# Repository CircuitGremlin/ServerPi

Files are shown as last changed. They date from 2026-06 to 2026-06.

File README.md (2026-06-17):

[Information](#information)\
[Key features](#key-features)\
[Case](#case)\
[PCB](#pcb)\
[Bill of materials](#bill-of-materials)\
[Installation](#installation)\
[Led configuration](#led-configuration)\
[Oled stats](#oled-stats)\
[Known issues](#known-issues)\
[To do](#to-do)\
[Contribute](#contribute)

# Information
A few years ago, I built a server with a CM4, a CM4IO board and an asm1064 PCI-e card. With the release of the Raspberry Pi 5, I wanted to build a new server. I prefer the Geekworm X1009 to the Radxa Penta because it has five ports and the power connector is on the back.

This server case isn't the smallest, but I'm happy with it so far. It sits on my media unit and is always visible, so it needs to look good.

# Key features
- 149x194x88mm (width x depth x height(without feet))
- Supports 5x2.5" HDD up to 15mm on caddy's
- Access to the SD card, power button and LED on the side behind the ventilation grille.
- Custom PCB and software (Easy configure led's wia Webserver)
- Oled stats (https://github.com/CircuitGremlin/RPiOledStatsLuma)

## Case
[3D print files](/3d_print_files)<br />
[Plywood panel plans](/plywood_panel_plans)

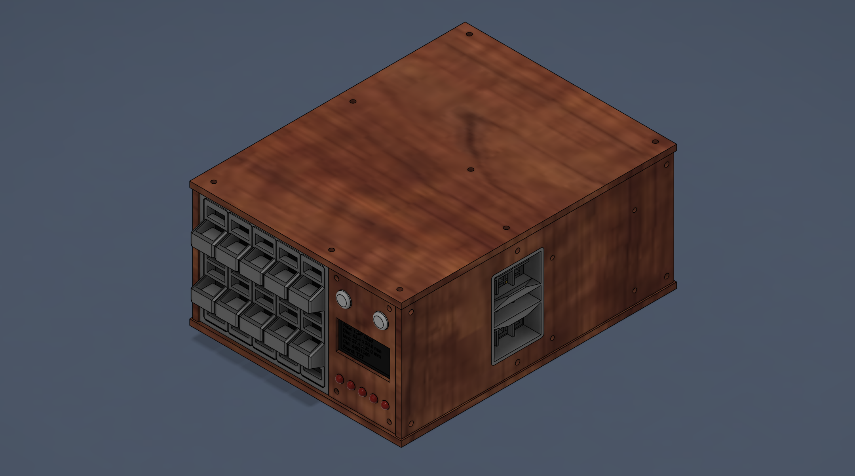
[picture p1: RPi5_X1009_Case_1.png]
picture alt RPi5 X1009 Case

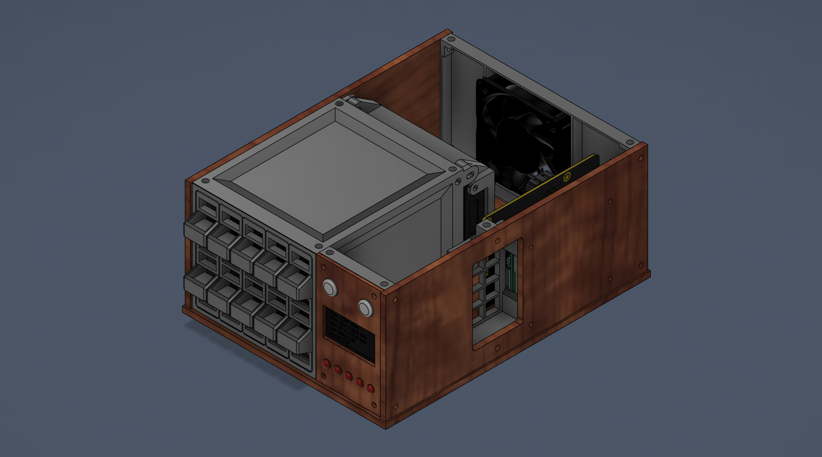
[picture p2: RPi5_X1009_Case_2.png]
picture alt RPi5 X1009 Case


## PCB
[Schematic](pcb_files/Schematic_RPi5_ServerPi_v0.03.pdf)<br />
[Preview](/pcb_files/PCB_RPi5_ServerPi_v0.03.pdf)<br />
[Files](/pcb_files)

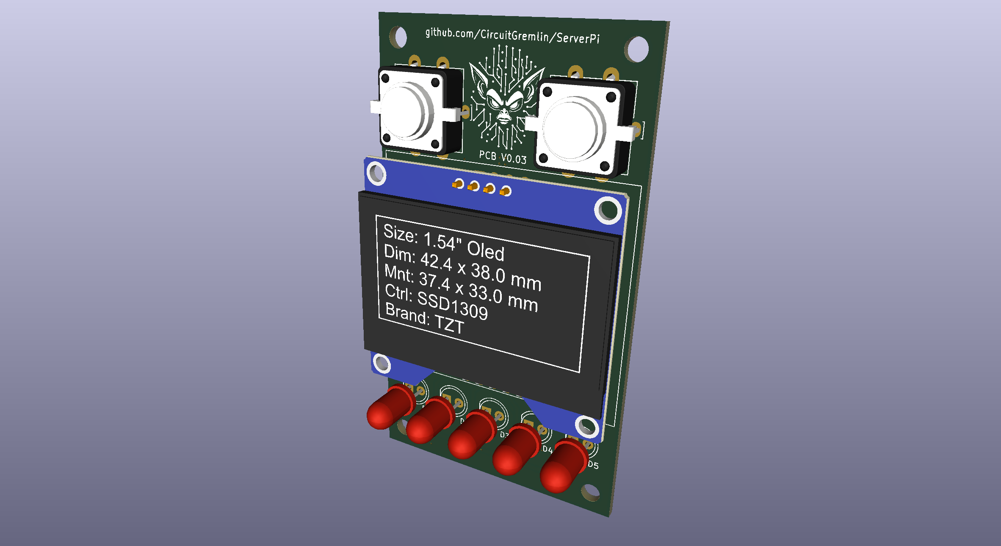
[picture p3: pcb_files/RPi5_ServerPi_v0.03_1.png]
picture alt RPi5 ServerPi v0.03

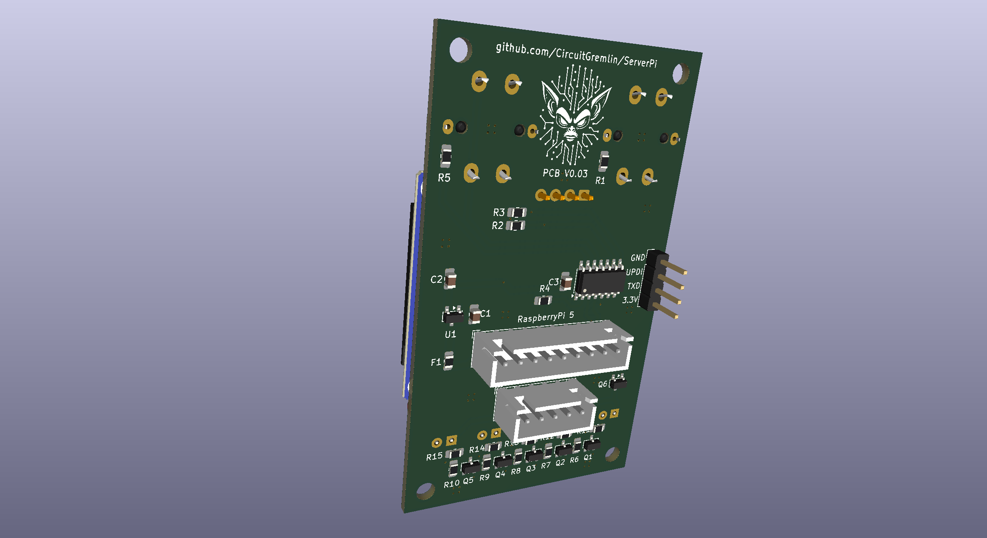
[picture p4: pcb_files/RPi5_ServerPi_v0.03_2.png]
picture alt RPi5 ServerPi v0.03


## Bill of materials
### Raspberry Pi hardware
Quantity  | Part
:---------|:-----
1 | Raspberry Pi 5
1 | Geekworm X1009 PCIe to 5-Port SATA Shield for Raspberry Pi 5
1 | Geekworm H505 Active Cooler for Raspberry Pi 5
5 | Sata male to female adapter
5 | 10cm Sata cable
1 | Raspberry Pi 5 RTC Batterie
1 | 60x15mm or 60x10mm fan (12V PWM recomended)

### Case hardware
Quantity  | Part | Dimension | Purpose
:---------|:-----|:----------|:-------
45  | Stainless screw | M3x6mm - M3x7mm | Case, PCB, fan
45  | Heatinsert | M3xL3xOD4.5mm | Case, PCB, fan
4   | Standoff | M2.5x6mm | Raspberry Pi mount
4   | Screw | M2.5x6mm - M2.5x8mm | Raspberry Pi mount

### Plywood panels
Quantity  | Part | Dimension
:---------|:-----|:----------
2 | Top/Bottom | 194x149x4mm
2 | Left/Right | 192x80x4mm
1 | Front | 80x48x2mm

### PCB
Quantity  | Part | Value
:---------|:-----|:----------
1 | PCB | JLCPCB
1 | Oled | 1.54"
2 | Button | 12X12X7,3mm 6Pin with led
5 | Led | 5mm
1 | Connector JST XH | 5pin male & female & crimp contacts
1 | Connector JST XH | 9pin male & female & crimp contacts
2 | Pinheader 2.54mm | 4pin
1 | MCU SOIC-14 | ATtiny1614
1 | LDO SOT-23 | MCP1702T-3302ECB
5 | PNP transistor SOT-23 | BC857
1 | NPN transistor SOT-23 | BC847
2 | Resistor 0805 | 30R
5 | Resistor 0805 | 270R
2 | Resistor 0805 | 4K7
1 | Resistor 0805 | 10K
6 | Resistor 0805 | 33K
2 | Capacitor 0805 | 1μF 
1 | Capacitor 0805 | 0.1μF / 100nF
1 | Fuse 0805 | <100mA (optional)
14 | Jumperwire | 15-20cm with female housing
1 | Combo | Male PWM fan connector & cable

# Installation
## Install needed packages and enable I2C interface
[/install_packages_and_i2c.sh](/install_packages_and_i2c.sh)
```sh
wget -qO- https://raw.githubusercontent.com/CircuitGremlin/ServerPi/main/install_packages_and_i2c.sh | bash
```

Reboot if necessary
```sh
sudo reboot
```
## Install this repository
[/install_repo.sh](/install_repo.sh)
```sh
wget -qO- https://raw.githubusercontent.com/CircuitGremlin/ServerPi/main/install_repo.sh | bash
```
## Install services
[/install_service.sh](/install_service.sh), [/python/serverpi-send-intermediate-status/install.sh](/python/serverpi-send-intermediate-status/install.sh), [/python/serverpi-send-ready-status/install.sh](/python/serverpi-send-ready-status/install.sh)
```sh
wget -qO- https://raw.githubusercontent.com/CircuitGremlin/ServerPi/main/install_service.sh | bash
```
## Install fan
[/install_fan.sh](/install_fan.sh)
```sh
wget -qO- https://raw.githubusercontent.com/CircuitGremlin/ServerPi/main/install_fan.sh | bash
```

Reboot if necessary
```sh
sudo reboot
```

# Led configuration
Activate virtual python environment
```sh
source ~/ServerPi/python/pyvenv/bin/activate
```
Run python led server
```sh
python ~/ServerPi/python/serverpi-led-server/serverpi-led-server.py
```
Go to http://your-server:3001 and set your led brightness. To stop the server, press Ctrl+C.

# Oled stats
I use my own python script: https://github.com/CircuitGremlin/RPiOledStatsLuma

### Setup button
Edit `config.yml`
```sh
nano ~/RPiOledStatsLuma/config.yml
```
Setup button like so
```yaml
buttons:
  - gpio: "17"
    func: "next"
```

# Known issues
- None yet ;)

# To do
- Setup power button hold function (c++ and python) to reboot Raspberry Pi
- Setup status led (Secondary button) to visualize status, disk health, etc.

# Contribute
Let me know if you found an issue or like to contribute. Thank you!

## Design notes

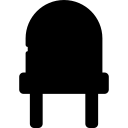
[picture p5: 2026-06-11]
python/serverpi-led-server/html/img/led-128.png

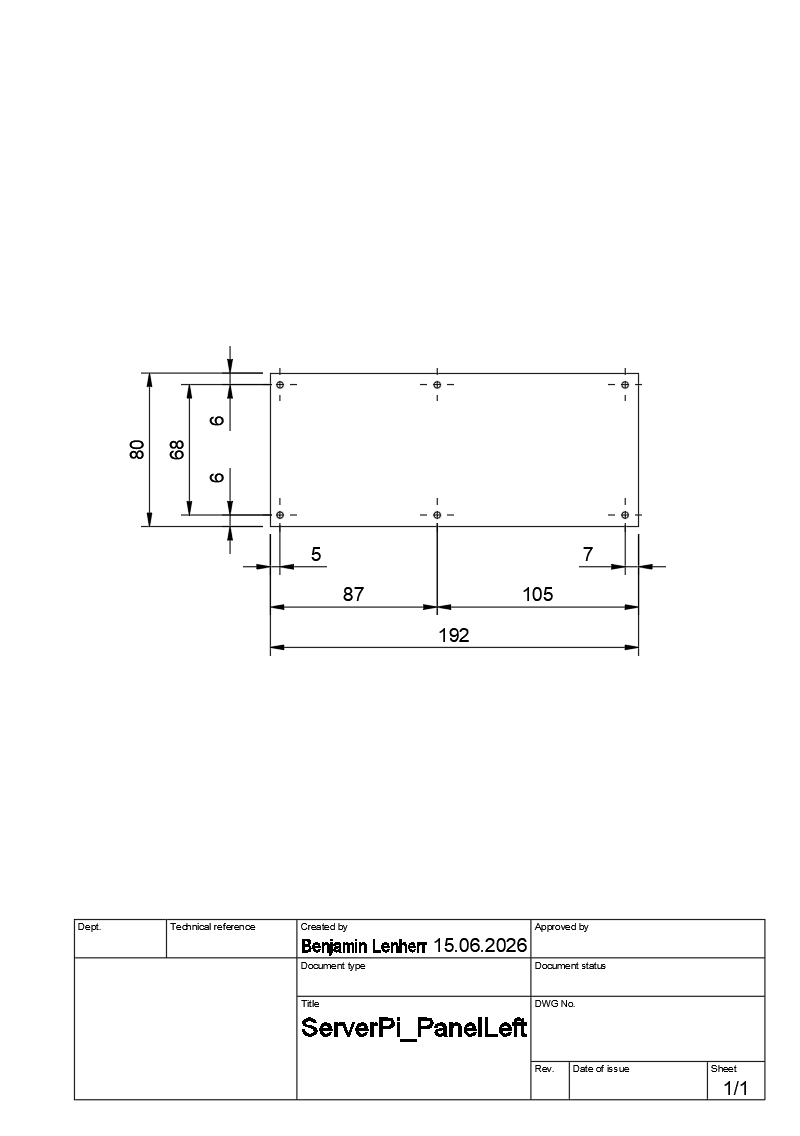
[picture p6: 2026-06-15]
plywood_panel_plans/ServerPi_PanelLeft.png

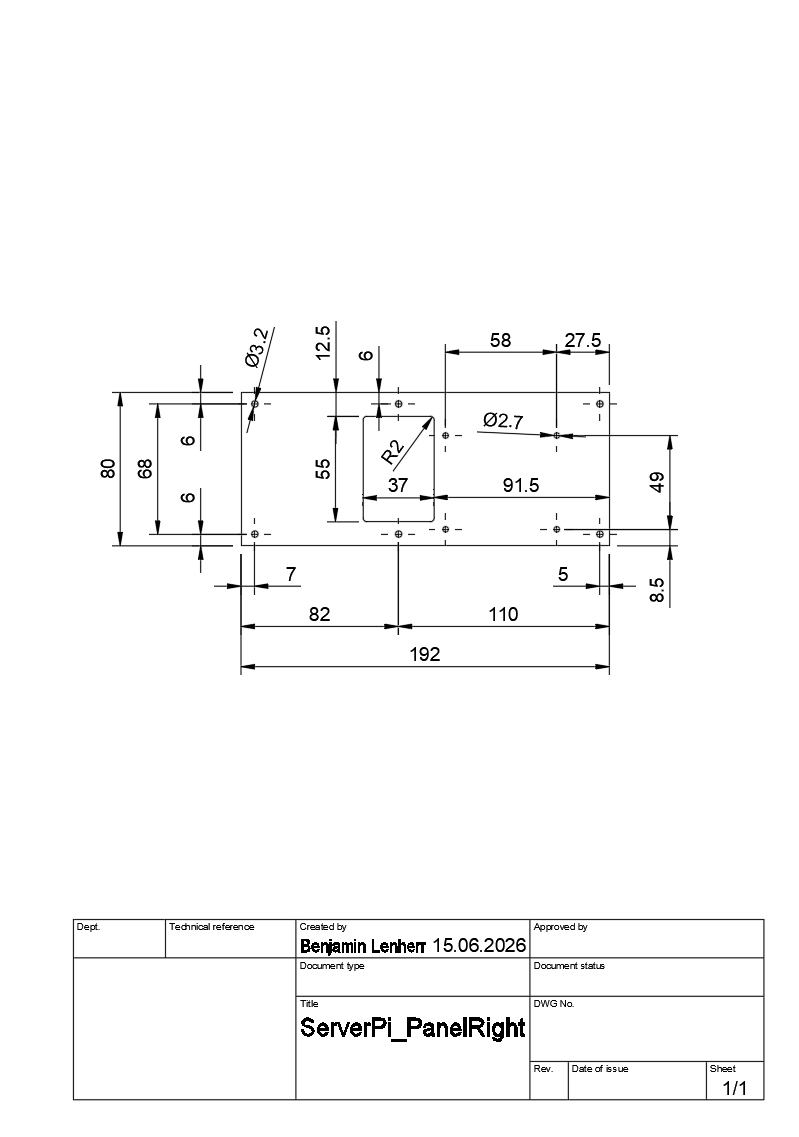
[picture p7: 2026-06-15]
plywood_panel_plans/ServerPi_PanelRight.png

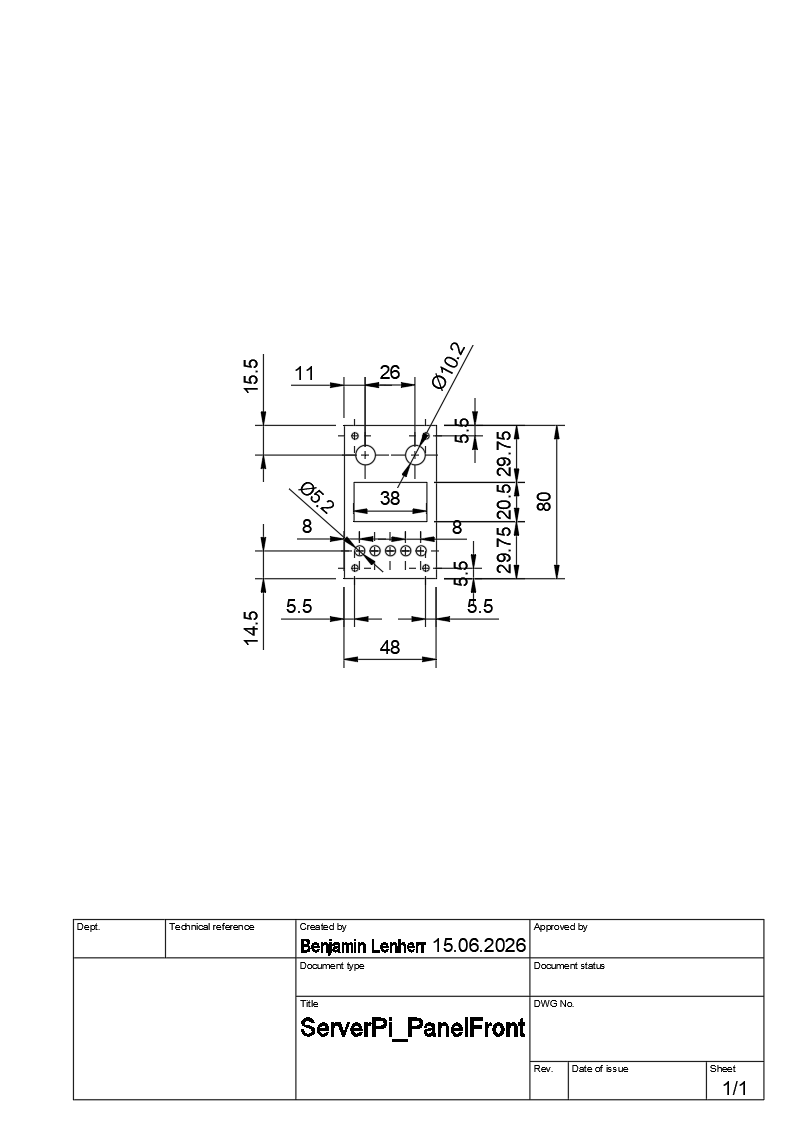
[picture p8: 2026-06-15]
plywood_panel_plans/ServerPi_PanelFront.png

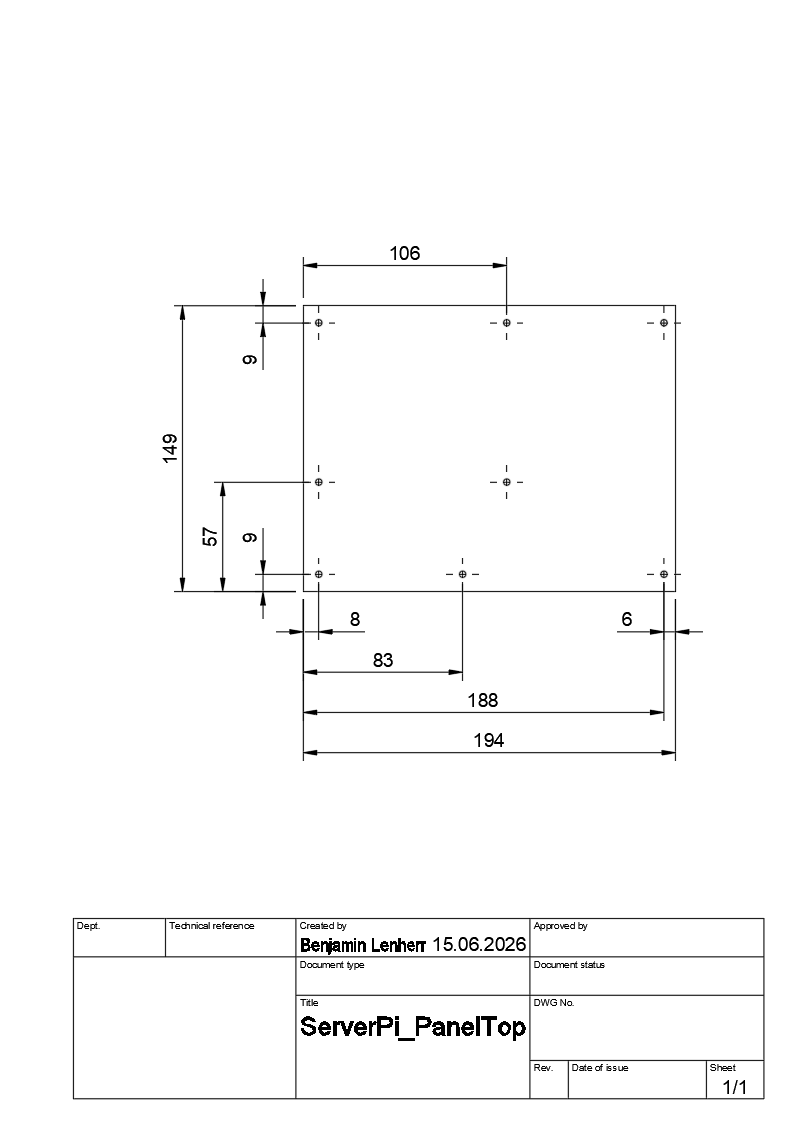
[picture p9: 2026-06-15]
plywood_panel_plans/ServerPi_PanelTop.png

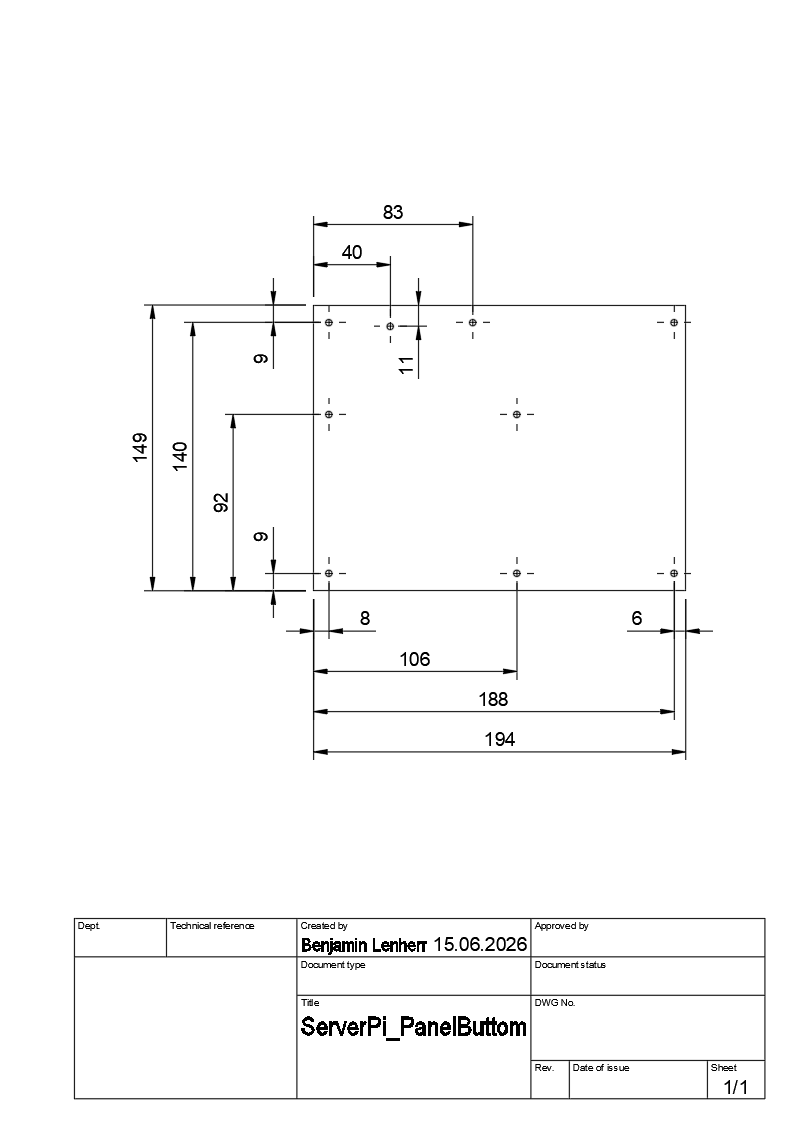
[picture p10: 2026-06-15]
plywood_panel_plans/ServerPi_PanelBottom.png

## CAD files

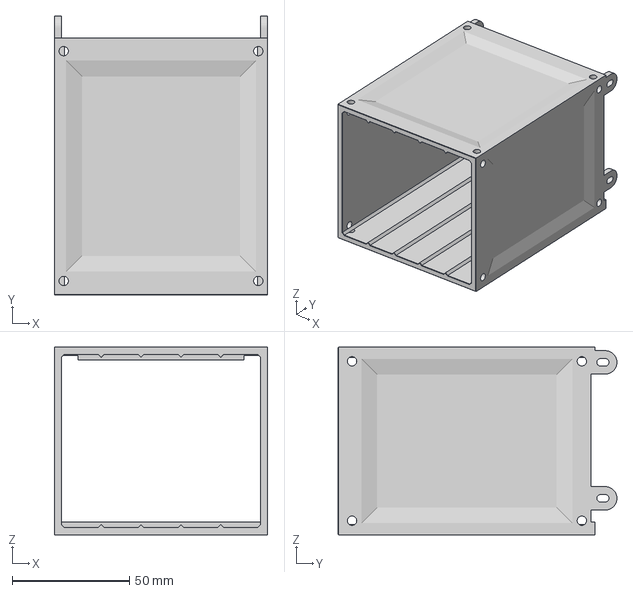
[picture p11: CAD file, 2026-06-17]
3d_print_files/ServerPi_CaddyCage.3mf
91.0 x 119.0 x 80.0 mm

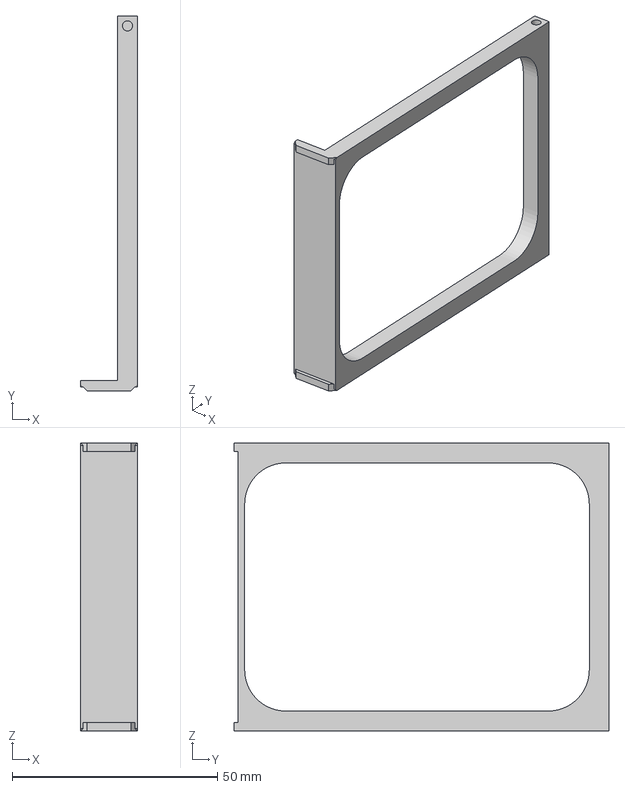
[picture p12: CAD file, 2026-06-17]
3d_print_files/ServerPi_CaddyDummy.3mf
13.8 x 91.3 x 70.0 mm

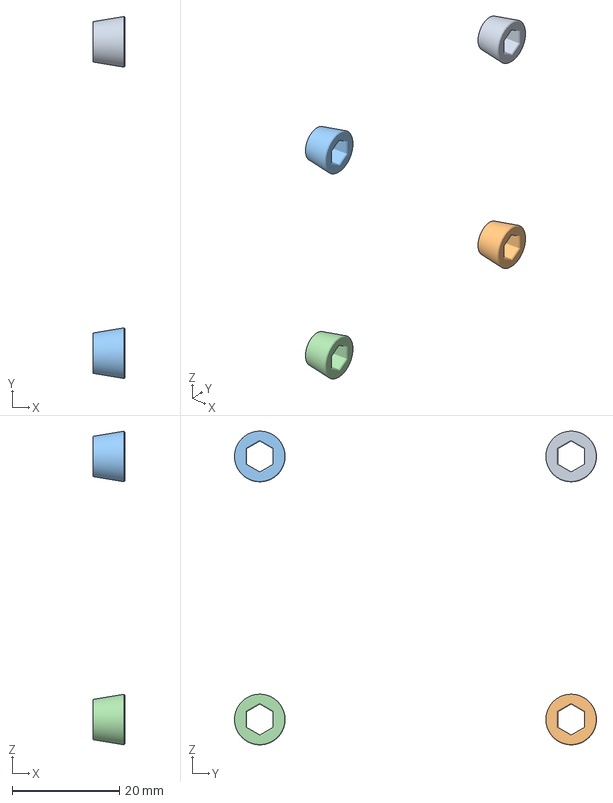
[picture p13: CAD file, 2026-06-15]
3d_print_files/ServerPi_RPiStandoffSleve.3mf
6.00 x 67.4 x 58.4 mm
Körper1
Körper2
Körper3
Körper4

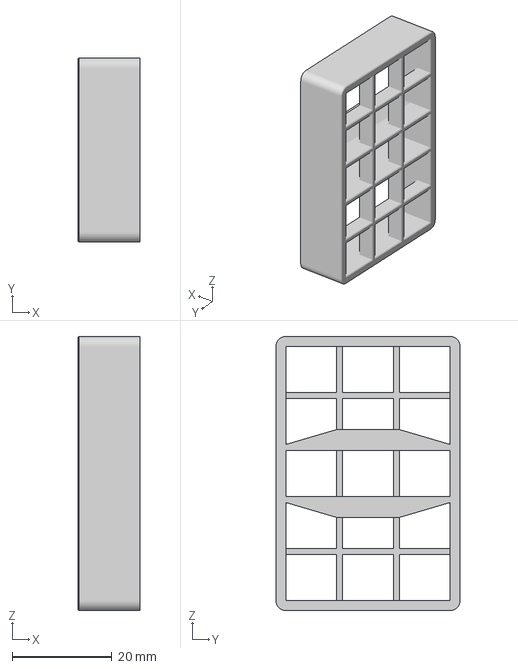
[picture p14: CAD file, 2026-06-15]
3d_print_files/ServerPi_SideCoolingGrill.3mf
12.5 x 37.0 x 55.0 mm

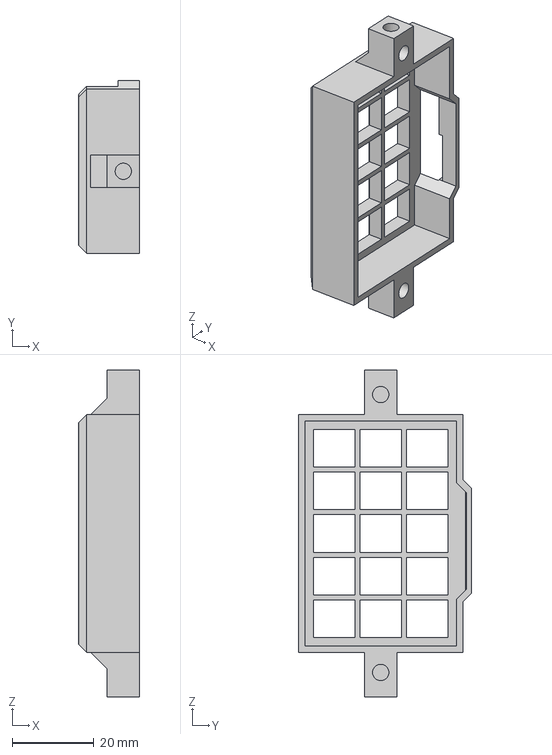
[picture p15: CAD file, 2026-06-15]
3d_print_files/ServerPi_SideCoolingFrame.3mf
15.0 x 42.3 x 80.0 mm

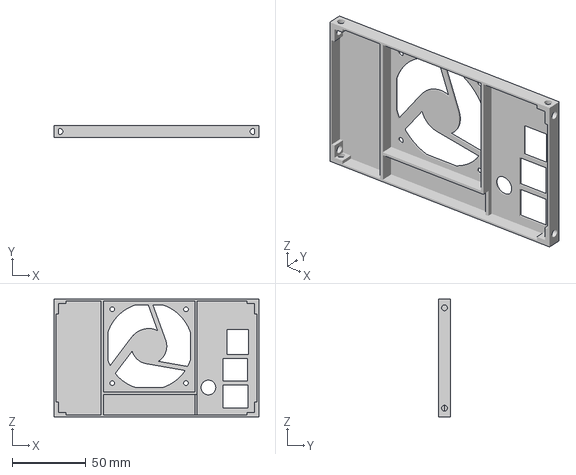
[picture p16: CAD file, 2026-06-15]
3d_print_files/ServerPi_RearFrame.3mf
139.0 x 8.00 x 80.0 mm

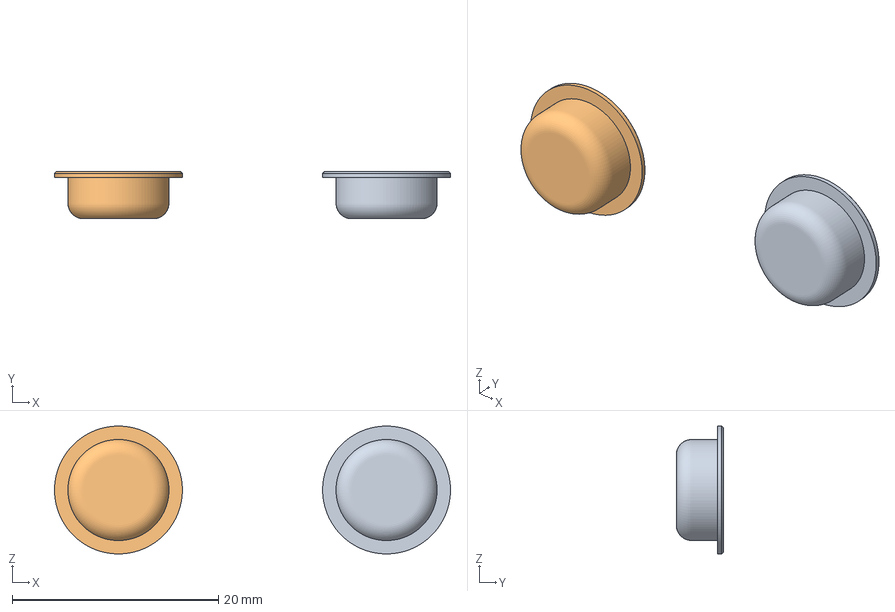
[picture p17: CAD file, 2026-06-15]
3d_print_files/ServerPi_ButtonCaps.3mf
38.4 x 4.60 x 12.4 mm
Körper1
Körper2

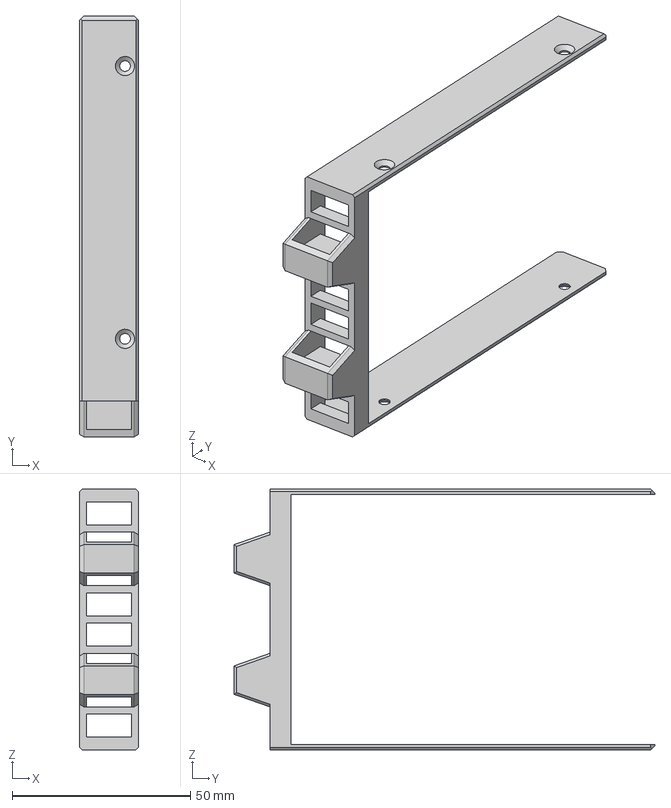
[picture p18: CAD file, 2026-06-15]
3d_print_files/ServerPi_Caddy.3mf
16.5 x 118.0 x 73.2 mm

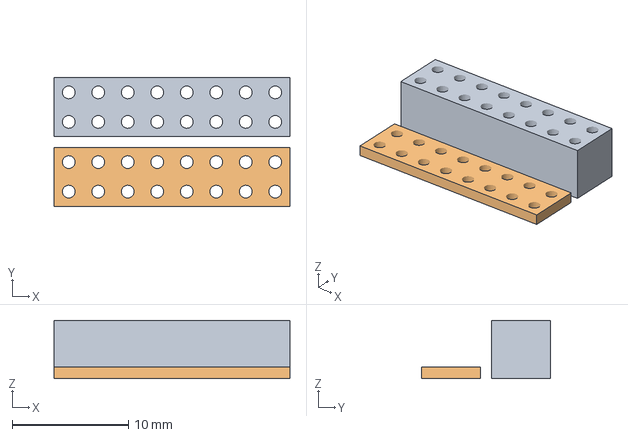
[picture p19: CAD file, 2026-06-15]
3d_print_files/ServerPi_PinheaderSpacer.3mf
20.3 x 11.1 x 5.00 mm
Körper1
Körper2

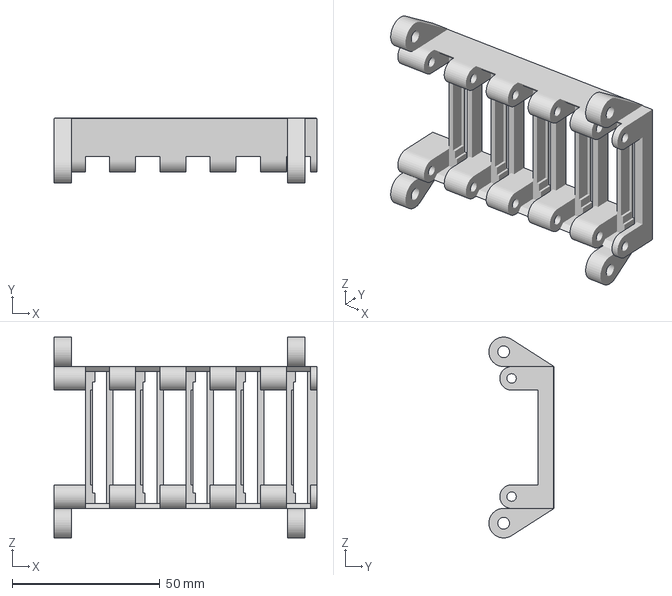
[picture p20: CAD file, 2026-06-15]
3d_print_files/ServerPi_SataBracket.3mf
89.0 x 22.1 x 68.0 mm

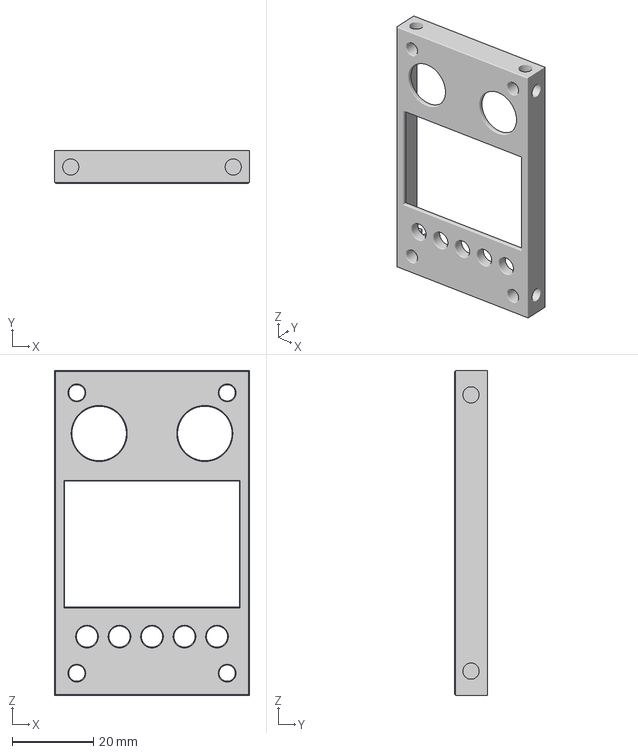
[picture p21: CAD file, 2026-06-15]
3d_print_files/ServerPi_FrontFrame.3mf
48.0 x 8.00 x 80.0 mm

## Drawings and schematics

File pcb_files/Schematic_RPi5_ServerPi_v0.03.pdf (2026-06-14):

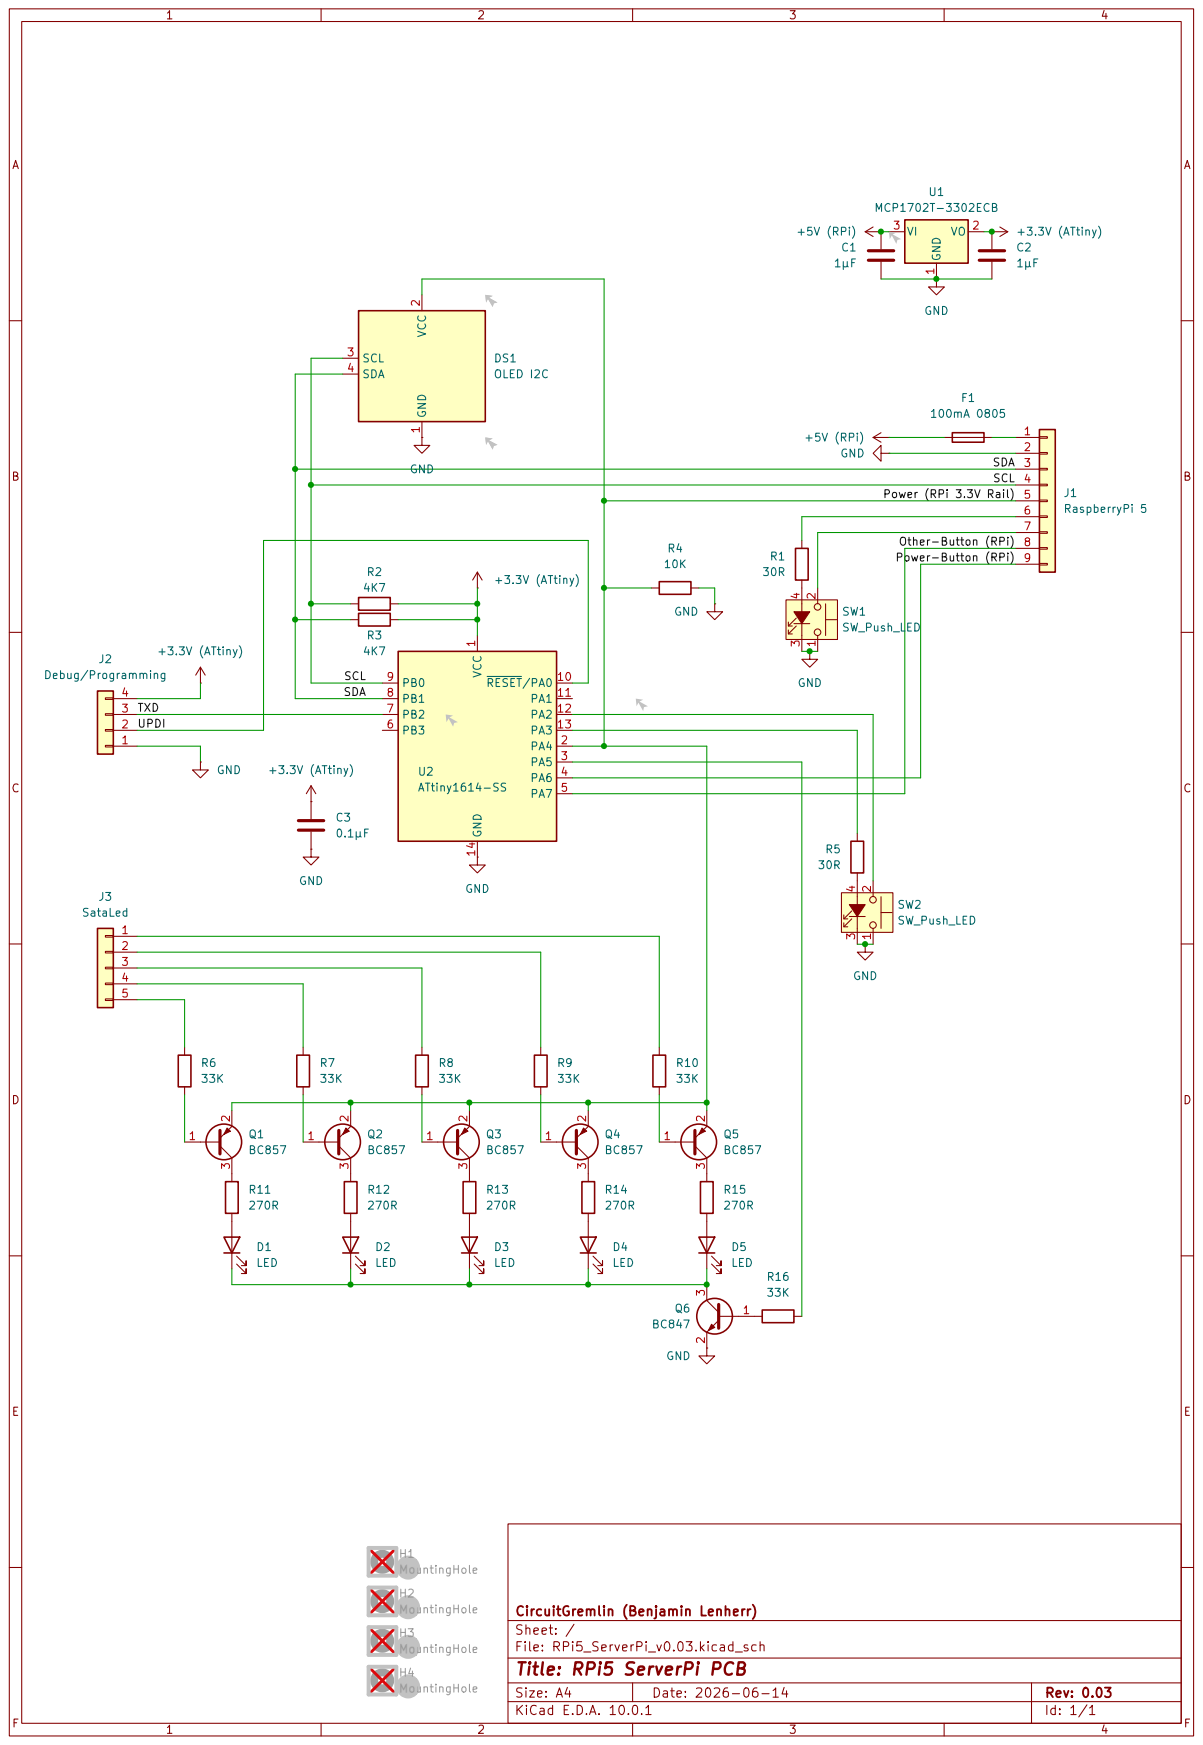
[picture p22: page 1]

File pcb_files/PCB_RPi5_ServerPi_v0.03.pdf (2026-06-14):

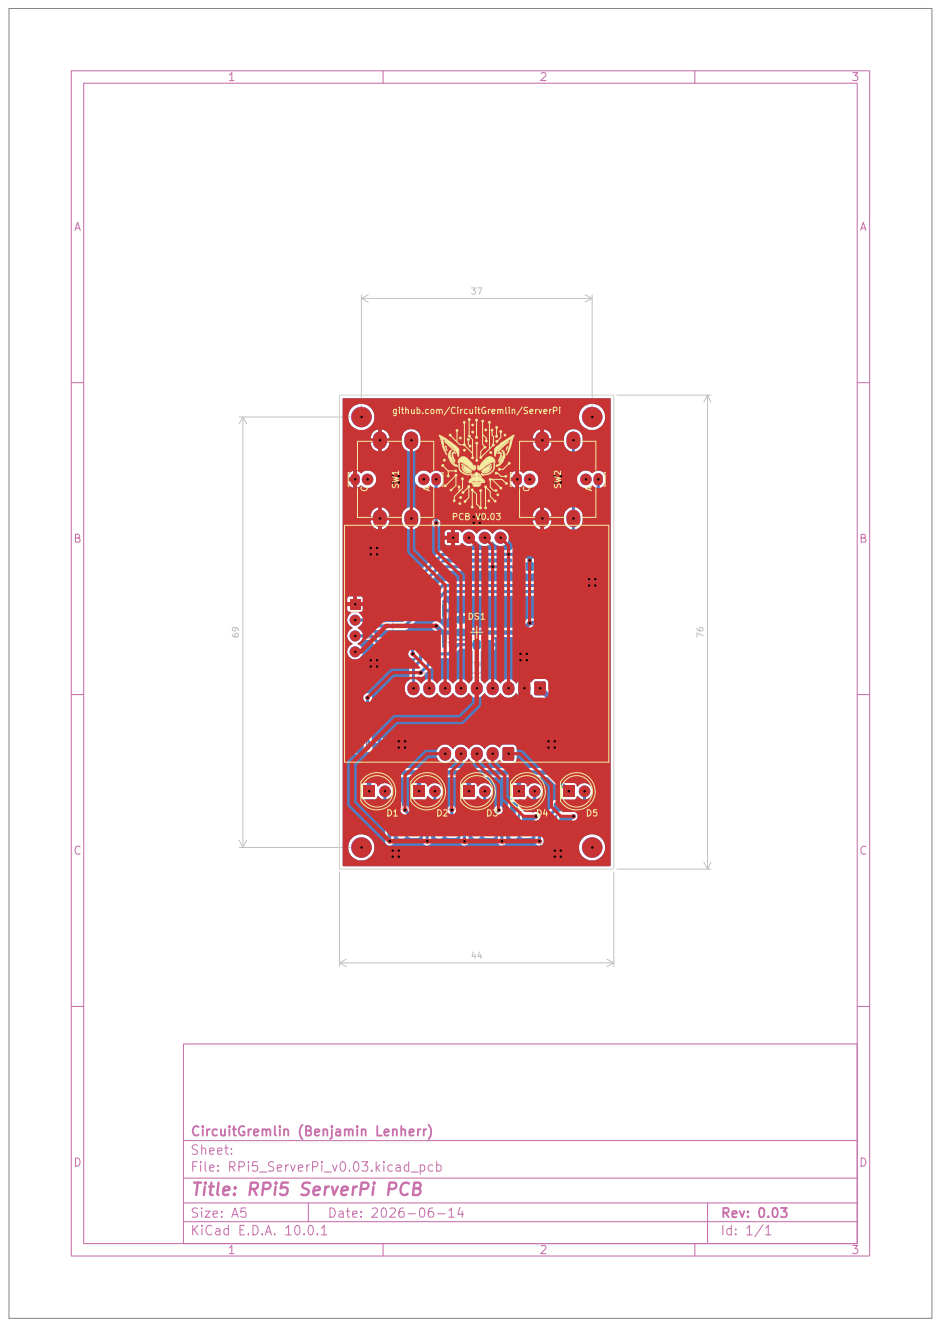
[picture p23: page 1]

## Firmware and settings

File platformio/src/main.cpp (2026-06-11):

#include <Arduino.h> // Always include Arduino.h

// Standard librarys
#include <EEPROM.h>
#include <Wire.h>

// Installed librarys via platformio.ini
// ...

// Project related librarys
// ...

void (*resetFunc)(void) = 0; // declare reset fuction at address 0

// Eeprom
#ifndef EEPROM_ADDRESS_FIRST_RUN_DONE_KEY
#define EEPROM_ADDRESS_FIRST_RUN_DONE_KEY 32 // Eeprom address
#endif
#ifndef EEPROM_ADDRESS_CONFIG
#define EEPROM_ADDRESS_CONFIG 64 // Eeprom address
#endif

// Button
#ifndef POWER_BUTTON_PIN
#define POWER_BUTTON_PIN PIN_PA2 // Button input pin active LOW
#endif
#ifndef POWER_BUTTON_DEBOUNCE_TIME
#define POWER_BUTTON_DEBOUNCE_TIME 50 // Value in milliseconds(ms)
#endif
#ifndef POWER_BUTTON_HOLD_TIME
#define POWER_BUTTON_HOLD_TIME 2000 // Value in milliseconds(ms)
#endif
volatile uint32_t powerButtonFirstTime = millis();
volatile bool powerButtonLastState = HIGH;

// Pwm
#define LED_PWM_STEPS 101
const uint8_t pwmTable[LED_PWM_STEPS] = {0, 0, 0, 0, 0, 0, 0, 0, 0, 1, 1, 1, 1, 1, 1, 1, 1, 1, 2, 2, 2, 2, 2, 2, 3, 3, 3, 3, 4, 4, 4, 4, 5, 5, 5, 6, 6, 7, 7, 7, 8, 8, 9, 10, 10, 11, 11, 12, 13, 14, 15, 15, 16, 17, 18, 20, 21, 22, 23, 25, 26, 28, 29, 31, 33, 35, 37, 39, 42, 44, 47, 49, 52, 55, 59, 62, 66, 70, 74, 78, 83, 87, 92, 98, 103, 109, 116, 123, 130, 137, 145, 154, 163, 172, 182, 192, 204, 215, 228, 241, 255};
// https://diarmuid.ie/blog/pwm-exponential-led-fading-on-arduino-or-other-platforms

// Power led
#ifndef POWER_LED_FADE_CYCLE_LENGTH
#define POWER_LED_FADE_CYCLE_LENGTH 1000 // Value in milliseconds(ms), 0-5000 (Default 1000)
#endif
volatile uint8_t powerLedFadeDelay;
volatile int8_t powerLedBrightness = 0;
volatile uint32_t powerLedLastFade = millis();
enum
{
    POWER_LED_OFF,
    POWER_LED_ON,
    POWER_LED_FADE_UP,
    POWER_LED_FADE_DOWN,
};
volatile uint8_t powerLedFadeDirection = POWER_LED_OFF;

// Settings
#ifndef FIRST_RUN_DONE_KEY
#define FIRST_RUN_DONE_KEY 0x2E737605 // Unsigned long(uint32) as HEX number
#endif
#ifndef TEST_MODE_DURATION
#define TEST_MODE_DURATION = 5000 // 5 seconds
#endif
enum
{
    POWER_LED_MIN_BRT,
    POWER_LED_MAX_BRT,
    SATA_LED_BRT
};
const uint8_t defaultBrightness[3] = {
    20,  // Default power led min brightness
    100, // Default power led max brightness
    100  // Default sata led brightness
};
volatile uint8_t storedBrightness[3];
volatile uint8_t testBrightness[3];
volatile uint32_t firstRunDoneKey = 0;
bool testMode = false;
volatile uint32_t lastTestModeActivatedMillis = millis();
void resetTestMode()
{
#ifdef DEBUG
    Serial.println(F("[TEST MODE] Reset"));
#endif
    testMode = true;
    lastTestModeActivatedMillis = millis();
}

// RaspberryPi
#ifndef RPI_BUTTON_SIGNAL_LENGTH
#define RPI_BUTTON_SIGNAL_LENGTH 250 // Value in milliseconds(ms)
#endif
volatile uint32_t buttonWriteFirstTime = millis();
volatile bool lastRpiPowerInput = LOW;
volatile uint8_t internalRunlevel = NULL;

// I2C
#define I2C_ADDRESS 0x08 // 8
uint8_t cmd[5];          // 5 bytes for uint32 data
uint8_t indexByte = 0;   // Reset index byte
uint8_t registerToWrite = NULL;
uint32_t lastRegisterReceive = millis(); // Milliseconds[ms]
uint8_t registerWriteTimeout = 100;      // Milliseconds[ms]
// RPi runlevel register
#define I2C_RUNLEVEL_REG 0xA0   // RPi runlevel register: 160
#define I2C_RUNLEVEL_OFF 0x00   // Off byte:                    0
#define I2C_RUNLEVEL_INTER 0x01 // Intermediate byte:           1
#define I2C_RUNLEVEL_READY 0x02 // Ready byte:                   2
// RPi status register
#define I2C_STATUS_REG 0xA1 // RPi runlevel register: 161
// Default brightness register
#define I2C_DEFAULT_PWR_LED_MIN_BRT_REG 0xB0 // Default power led min brightness register:  176
#define I2C_DEFAULT_PWR_LED_MAX_BRT_REG 0xB1 // Default power led max brightness register:  177
#define I2C_DEFAULT_SATA_LED_BRT_REG 0xB2    // Default sata led brightness register:       178
#define I2C_DEFAULT_BRT_STRUCT_REG 0xBF      // Default brightness structure register:      191
// Stored brightness register
#define I2C_STORED_PWR_LED_MIN_BRT_REG 0xC0 // Stored power led min brightness register:    192
#define I2C_STORED_PWR_LED_MAX_BRT_REG 0xC1 // Stored power led max brightness register:    193
#define I2C_STORED_SATA_LED_BRT_REG 0xC2    // Stored sata led brightness register:         194
#define I2C_STORED_BRT_STRUCT_REG 0xCF      // Stored brightness structure register:        207
// Test brightness register
#define I2C_TEST_PWR_LED_MIN_BRT_REG 0xD0 // Test power led min brightness register:    208
#define I2C_TEST_PWR_LED_MAX_BRT_REG 0xD1 // Test power led max brightness register:    209
#define I2C_TEST_SATA_LED_BRT_REG 0xD2    // Test sata led brightness register:         210
#define I2C_TEST_BRT_STRUCT_REG 0xDF      // Test brightness structure register:        223
void process(uint8_t *cmd)
{
    registerToWrite = NULL; // Reset register to write

    switch (cmd[0])
    {
    case I2C_RUNLEVEL_REG: // RPi runlevel register
#ifdef DEBUG
        Serial.printf("[I2C REGISTER] RPi runlevel (%#04X), %i (%#04X)\n\r", cmd[0], cmd[1], cmd[1]);
#endif
        internalRunlevel = cmd[1];
        if (cmd[1] == I2C_RUNLEVEL_INTER)
            powerLedFadeDirection = POWER_LED_FADE_DOWN;
        break;

    case I2C_STORED_PWR_LED_MIN_BRT_REG: // Stored power led min brightness register
    case I2C_STORED_PWR_LED_MAX_BRT_REG: // Stored power led max brightness register
    case I2C_STORED_SATA_LED_BRT_REG:    // Stored sata led brightness register
        if (cmd[1] == 1)                 // Were 1 bytes of data received?
        {
#ifdef DEBUG
            Serial.print(F("[I2C REGISTER] Stored brightness: "));
            Serial.println(cmd[2]);
#endif
            const uint8_t index = cmd[0] - I2C_STORED_PWR_LED_MIN_BRT_REG;
            storedBrightness[index], testBrightness[index] = cmd[2];
            EEPROM.put(EEPROM_ADDRESS_CONFIG, storedBrightness);
            resetTestMode();
            powerLedFadeDelay = round(float(POWER_LED_FADE_CYCLE_LENGTH) / (storedBrightness[POWER_LED_MAX_BRT] - storedBrightness[POWER_LED_MIN_BRT]) / 2);
            switch (powerLedFadeDirection)
            {
            case POWER_LED_ON:
                powerLedFadeDirection = POWER_LED_FADE_DOWN; // Set power led fade down
                break;
            case POWER_LED_OFF:
                powerLedFadeDirection = POWER_LED_FADE_UP; // Set power led fade up
                break;
            default:
                break;
            }
            EEPROM.put(EEPROM_ADDRESS_CONFIG, storedBrightness);
        }
        break;
    case I2C_STORED_BRT_STRUCT_REG: // Stored brightness structure register
        if (cmd[1] == 3)            // Were 3 bytes of data received?
        {
#ifdef DEBUG
            Serial.print(F("[I2C REGISTER] Stored brightness: "));
            Serial.print(cmd[2]);
            Serial.print(F(", "));
            Serial.print(cmd[3]);
            Serial.print(F(", "));
            Serial.println(cmd[4]);
#endif
            for (uint8_t i = 0; i < 3; i++)
                storedBrightness[i], testBrightness[i] = cmd[2 + i];
            EEPROM.put(EEPROM_ADDRESS_CONFIG, storedBrightness);
            resetTestMode();
            powerLedFadeDelay = round(float(POWER_LED_FADE_CYCLE_LENGTH) / (storedBrightness[POWER_LED_MAX_BRT] - storedBrightness[POWER_LED_MIN_BRT]) / 2);
            switch (powerLedFadeDirection)
            {
            case POWER_LED_ON:
                powerLedFadeDirection = POWER_LED_FADE_DOWN; // Set power led fade down
                break;
            case POWER_LED_OFF:
                powerLedFadeDirection = POWER_LED_FADE_UP; // Set power led fade up
                break;
            default:
                break;
            }
        }
        break;

    case I2C_TEST_PWR_LED_MIN_BRT_REG: // Test power led min brightness register
    case I2C_TEST_PWR_LED_MAX_BRT_REG: // Test power led max brightness register
    case I2C_TEST_SATA_LED_BRT_REG:    // Test sata led brightness register
#ifdef DEBUG
        Serial.print(F("[I2C REGISTER] Test brightness: "));
        Serial.println(cmd[1]);
#endif
        const uint8_t index = cmd[0] - I2C_TEST_PWR_LED_MIN_BRT_REG;
        testBrightness[index] = cmd[1];
        resetTestMode();
        powerLedFadeDelay = round(float(POWER_LED_FADE_CYCLE_LENGTH) / (testBrightness[POWER_LED_MAX_BRT] - testBrightness[POWER_LED_MIN_BRT]) / 2);
        switch (powerLedFadeDirection)
        {
        case POWER_LED_ON:
            powerLedFadeDirection = POWER_LED_FADE_DOWN; // Set power led fade down
            break;
        case POWER_LED_OFF:
            powerLedFadeDirection = POWER_LED_FADE_UP; // Set power led fade up
            break;
        default:
            break;
        }
        break;
    case I2C_TEST_BRT_STRUCT_REG: // Test brightness structure register
        if (cmd[1] == 3)          // Were 3 bytes of data received?
        {
#ifdef DEBUG
            Serial.print(F("[I2C REGISTER] Test brightness: "));
            Serial.println(cmd[2]);
            Serial.print(F(", "));
            Serial.print(cmd[3]);
            Serial.print(F(", "));
            Serial.println(cmd[4]);
#endif
            for (uint8_t i = 0; i < 3; i++)
                testBrightness[i] = cmd[2 + i];
            resetTestMode();
            powerLedFadeDelay = round(float(POWER_LED_FADE_CYCLE_LENGTH) / (testBrightness[POWER_LED_MAX_BRT] - testBrightness[POWER_LED_MIN_BRT]) / 2);
            switch (powerLedFadeDirection)
            {
            case POWER_LED_ON:
                powerLedFadeDirection = POWER_LED_FADE_DOWN; // Set power led fade down
                break;
            case POWER_LED_OFF:
                powerLedFadeDirection = POWER_LED_FADE_UP; // Set power led fade up
                break;
            default:
                break;
            }
        }
        break;

    default:
        break;
    }

    registerToWrite = cmd[0];
    lastRegisterReceive = millis();
}
void readI2cData(int byteCount)
{
#ifdef DEBUG
    Serial.print(F("[I2C READ] Raw data: "));
#endif
    // Read i2c bus
    indexByte = 0;
    while (Wire.available())
    {
        const uint8_t tempChar = (uint8_t)Wire.read();
#ifdef DEBUG
        Serial.print(tempChar);
        Serial.print(F(" "));
#endif
        cmd[indexByte++] = tempChar; // Add temp char into command buffer and increment index
    }
#ifdef DEBUG
    Serial.println();
#endif
    if (cmd[0] != NULL) // Process command buffer
        process(cmd);
    for (uint8_t i = 0; i < sizeof(cmd); i++) // Clear command buffer
        cmd[i] = NULL;
}
void sendI2cData()
{
    if (registerToWrite != NULL)
    {
#ifdef DEBUG
        Serial.print(F("[I2C WRITE] Register: "));
        Serial.println(registerToWrite);
#endif
        switch (registerToWrite)
        {
        case I2C_RUNLEVEL_REG: // RPI runlevel register
            // Write internal runlevel
            Wire.write((const uint8_t *)&internalRunlevel, sizeof(internalRunlevel));
            break;
        case I2C_STATUS_REG: // RPI status register
            // Write status runlevel
            Wire.write((const uint8_t *)&internalRunlevel, sizeof(internalRunlevel));
            break;

        case I2C_DEFAULT_PWR_LED_MIN_BRT_REG: // Default power led min brightness register
        case I2C_DEFAULT_PWR_LED_MAX_BRT_REG: // Default power led max brightness register
        case I2C_DEFAULT_SATA_LED_BRT_REG:    // Default sata led brightness register
            // Write default brightness
            Wire.write((const uint8_t *)&defaultBrightness[registerToWrite - I2C_DEFAULT_PWR_LED_MIN_BRT_REG],
                       sizeof(defaultBrightness[registerToWrite - I2C_DEFAULT_PWR_LED_MIN_BRT_REG]));
            break;
        case I2C_DEFAULT_BRT_STRUCT_REG:
            // Write default brightness array
            Wire.write((const uint8_t *)&defaultBrightness, sizeof(defaultBrightness));
            break;

        case I2C_STORED_PWR_LED_MIN_BRT_REG: // Stored power led min brightness register
        case I2C_STORED_PWR_LED_MAX_BRT_REG: // Stored power led max brightness register
        case I2C_STORED_SATA_LED_BRT_REG:    // Stored sata led brightness register
            // Write stored brightness
            Wire.write((const uint8_t *)&storedBrightness[registerToWrite - I2C_STORED_PWR_LED_MIN_BRT_REG],
                       sizeof(storedBrightness[registerToWrite - I2C_STORED_PWR_LED_MIN_BRT_REG]));
            break;
        case I2C_STORED_BRT_STRUCT_REG: // Stored brightness structure register
            // Write stored brightness array
            Wire.write((const uint8_t *)&storedBrightness, sizeof(storedBrightness));
            break;

        case I2C_TEST_PWR_LED_MIN_BRT_REG: // Test power led min brightness register
        case I2C_TEST_PWR_LED_MAX_BRT_REG: // Test power led max brightness register
        case I2C_TEST_SATA_LED_BRT_REG:    // Test sata led brightness register
            // Write test brightness
            Wire.write((const uint8_t *)&testBrightness[registerToWrite - I2C_TEST_PWR_LED_MIN_BRT_REG],
                       sizeof(testBrightness[registerToWrite - I2C_TEST_PWR_LED_MIN_BRT_REG]));
            break;
        case I2C_TEST_BRT_STRUCT_REG: // Test brightness structure register
            // Write test brightness array
            Wire.write((const uint8_t *)&testBrightness, sizeof(testBrightness));
            break;

        default:
            break;
        }
    }
    registerToWrite = NULL; // Reset register to write
}
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
void loop()
{
    // I2c write register timeout
    if (millis() - lastRegisterReceive > registerWriteTimeout)
        registerToWrite = NULL;

    if (testMode) // Test mode
    {
        // Power led output sequence
        if (powerLedFadeDirection == POWER_LED_FADE_UP || powerLedFadeDirection == POWER_LED_FADE_DOWN)
        {
            const uint32_t powerLedThisFade = millis();
            // if (powerLedThisFade - powerLedLastFade >= POWER_LED_FADE_DELAY)
            if (powerLedThisFade - powerLedLastFade >= powerLedFadeDelay)
            {
                if (powerLedFadeDirection == POWER_LED_FADE_UP)
                {
                    powerLedBrightness++; // Increase power led brightness
                    if (powerLedBrightness > testBrightness[POWER_LED_MAX_BRT])
                    {
                        powerLedBrightness = testBrightness[POWER_LED_MAX_BRT] - 1;
                        powerLedFadeDirection = POWER_LED_FADE_DOWN; // Set power led fade down
                    }
                }
                else if (powerLedFadeDirection == POWER_LED_FADE_DOWN)
                {
                    powerLedBrightness--; // Decrease power led brightness
                    if (powerLedBrightness < testBrightness[POWER_LED_MIN_BRT])
                    {
                        powerLedBrightness = testBrightness[POWER_LED_MIN_BRT] + 1;
                        powerLedFadeDirection = POWER_LED_FADE_UP; // Set power led fade up
                    }
                }
                analogWrite(POWER_LED_PIN, pwmTable[powerLedBrightness]);
                powerLedLastFade = powerLedThisFade;
            }
        }

        // Sata led
        analogWrite(SATA_LED_PIN, pwmTable[testBrightness[SATA_LED_BRT]]);

        // Stop test mode
        if (millis() - lastTestModeActivatedMillis > TEST_MODE_DURATION)
        {
            analogWrite(SATA_LED_PIN, pwmTable[storedBrightness[SATA_LED_BRT]]);
            powerLedFadeDelay = round(float(POWER_LED_FADE_CYCLE_LENGTH) / (storedBrightness[POWER_LED_MAX_BRT] - storedBrightness[POWER_LED_MIN_BRT]) / 2);
            testMode = false;
        }
    }
    else // Normal mode
    {
        // Power button input sequence
        const bool powerButtonThisState = digitalRead(POWER_BUTTON_PIN);
        // Button first pressed
        if (powerButtonLastState == HIGH && powerButtonThisState == LOW)
        {
            powerButtonFirstTime = millis();
#ifdef DEBUG
            Serial.println(F("[BUTTON] First time"));
#endif
        }
        // Power button released
        if (powerButtonLastState == LOW && powerButtonThisState == HIGH)
        {
            // Power button held
            if (millis() - powerButtonFirstTime > POWER_BUTTON_HOLD_TIME)
            {
#ifdef DEBUG
                Serial.println(F("[BUTTON] Held"));
#endif
                if (digitalRead(RPI_POWER_INPUT_PIN) == HIGH) // RPi is powered on
                {
#ifdef DEBUG
                    Serial.println(F("[BUTTON] Held for power off RPi"));
#endif
                    if (millis() - buttonWriteFirstTime > RPI_BUTTON_SIGNAL_LENGTH * 2)
                    {
                        buttonWriteFirstTime = millis();                // Set first time
                        digitalWrite(RPI_POWER_BUTTON_OUTPUT_PIN, LOW); // Write RPi power button pin high
                    }
                }
            }
            // Button pressed
            else if (millis() - powerButtonFirstTime > POWER_BUTTON_DEBOUNCE_TIME)
            {
#ifdef DEBUG
                Serial.println(F("[BUTTON] Pressed"));
#endif
                if (digitalRead(RPI_POWER_INPUT_PIN) == LOW) // RPi is powered off
                {
#ifdef DEBUG
                    Serial.println(F("[BUTTON] Pressed for power on RPi"));
#endif
                    if (millis() - buttonWriteFirstTime > RPI_BUTTON_SIGNAL_LENGTH * 2)
                    {
                        buttonWriteFirstTime = millis();                // Set first time
                        digitalWrite(RPI_POWER_BUTTON_OUTPUT_PIN, LOW); // Write RPi power button pin high
                    }
                }
            }
        }
        powerButtonLastState = powerButtonThisState;

        // RPi power button output sequence
        if (millis() - buttonWriteFirstTime > RPI_BUTTON_SIGNAL_LENGTH) // Time exeeded
            digitalWrite(RPI_POWER_BUTTON_OUTPUT_PIN, HIGH);            // Write RPi power button pin low

        // RPi power input state sequence
        const bool thisRpiPowerInput = digitalRead(RPI_POWER_INPUT_PIN);
        if (thisRpiPowerInput == HIGH && lastRpiPowerInput == LOW)
        {
#ifdef DEBUG
            Serial.println(F("[RPI5] Power state: ON"));
#endif
            lastRpiPowerInput = thisRpiPowerInput;
            internalRunlevel = I2C_RUNLEVEL_INTER;
            powerLedFadeDirection = POWER_LED_FADE_UP;
        }
        else if (thisRpiPowerInput == LOW && lastRpiPowerInput == HIGH)
        {
#ifdef DEBUG
            Serial.println(F("[RPI5] Power state: OFF"));
#endif
            lastRpiPowerInput = thisRpiPowerInput;
            internalRunlevel = I2C_RUNLEVEL_OFF;
        }

        // Power led output sequence
        if (powerLedFadeDirection == POWER_LED_FADE_UP || powerLedFadeDirection == POWER_LED_FADE_DOWN)
        {
            const uint32_t powerLedThisFade = millis();
            // if (powerLedThisFade - powerLedLastFade >= POWER_LED_FADE_DELAY)
            if (powerLedThisFade - powerLedLastFade >= powerLedFadeDelay)
            {
                if (powerLedFadeDirection == POWER_LED_FADE_UP)
                {
                    powerLedBrightness++; // Increase power led brightness
                    if (powerLedBrightness > storedBrightness[POWER_LED_MAX_BRT])
                    {
                        if (internalRunlevel == I2C_RUNLEVEL_READY)
                        {
                            powerLedBrightness = storedBrightness[POWER_LED_MAX_BRT];
                            powerLedFadeDirection = POWER_LED_ON;
                        }
                        else
                        {
                            powerLedBrightness = storedBrightness[POWER_LED_MAX_BRT] - 1;
                            powerLedFadeDirection = POWER_LED_FADE_DOWN; // Set power led fade down
                        }
                    }
                }
                else if (powerLedFadeDirection == POWER_LED_FADE_DOWN)
                {
                    powerLedBrightness--; // Decrease power led brightness
                    if (powerLedBrightness < storedBrightness[POWER_LED_MIN_BRT])
                    {
                        if (internalRunlevel == I2C_RUNLEVEL_OFF)
                        {
                            if (powerLedBrightness <= 0)
                            {
                                powerLedBrightness = 0;
                                powerLedFadeDirection = POWER_LED_OFF;
                            }
                        }
                        else
                        {
                            powerLedBrightness = storedBrightness[POWER_LED_MIN_BRT] + 1;
                            powerLedFadeDirection = POWER_LED_FADE_UP; // Set power led fade up
                        }
                    }
                }
                analogWrite(POWER_LED_PIN, pwmTable[powerLedBrightness]);
                powerLedLastFade = powerLedThisFade;
            }
        }

        // Sata led
        analogWrite(SATA_LED_PIN, pwmTable[storedBrightness[SATA_LED_BRT]]);
    }
}

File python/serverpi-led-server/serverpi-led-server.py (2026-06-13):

"""
!/usr/bin/env python
This Python file uses the following encoding: utf-8

GPL-3.0 license

Server to configure a neopixel on TvPi IO-Board
"""

# Standard modules
import json
import os
import sys
import time
from http.server import BaseHTTPRequestHandler, HTTPServer, SimpleHTTPRequestHandler
from urllib.parse import urlparse, parse_qs
import socket

# Insatlled modules via pip
from smbus2 import SMBus

# Project related modules
# ...

# Webserver
PORT = 3001

# I2c
I2C_BUS = 1  # 1
I2C_ADDRESS = 0x08  # 8
I2C_WRITE_REPETITION = 1  # 1

# Default brightness register
I2C_DEFAULT_PWR_LED_MIN_BRT_REG = 0xB0  # 176
I2C_DEFAULT_PWR_LED_MAX_BRT_REG = 0xB1  # 177
I2C_DEFAULT_SATA_LED_BRT_REG = 0xB2  # 178
I2C_DEFAULT_BRT_STRUCT_REG = 0xBF  # 191
# Stored brightness register
I2C_STORED_PWR_LED_MIN_BRT_REG = 0xC0  # 192
I2C_STORED_PWR_LED_MAX_BRT_REG = 0xC1  # 193
I2C_STORED_SATA_LED_BRT_REG = 0xC2  # 194
I2C_STORED_BRT_STRUCT_REG = 0xCF  # 207
# Test brightness register
I2C_TEST_PWR_LED_MIN_BRT_REG = 0xD0  # 192 208
I2C_TEST_PWR_LED_MAX_BRT_REG = 0xD1  # 209
I2C_TEST_SATA_LED_BRT_REG = 0xD2  # 210
I2C_TEST_BRT_STRUCT_REG = 0xDF  # 223


def is_array_like(obj):
    """Check for array like value"""
    return hasattr(obj, "__len__")


def i2c_write_data(address, register, data, repetition):
    """Write i2c data"""
    for _ in range(10):
        try:
            with SMBus(I2C_BUS) as bus:
                for _ in range(repetition):
                    if is_array_like(data):
                        bus.write_block_data(address, register, data)
                    else:
                        bus.write_byte_data(address, register, data)
            return True
        except IOError:
            pass
            return None


def read_data(address, register, length):
    """Write i2c data"""
    for _ in range(10):
        try:
            with SMBus(I2C_BUS) as bus:
                data = bus.read_i2c_block_data(address, register, length)
                # print("RAW data: " + str(data))
                if len(data) == 1:
                    return data
                if len(data) == 3:
                    return [data[2], data[1], data[0]]
        except IOError:
            pass
            return None


class WebRequestHandler(BaseHTTPRequestHandler):
    def do_GET(self):

        # Serve '/img/*'
        if self.path.startswith("/img/"):
            with open(os.path.join(sys.path[0], "html" + self.path), "rb") as fh:
                self.send_response(200)
                self.send_header("Content-type", "image/png")
                self.end_headers()
                self.wfile.write(fh.read())

        # Serve '/' or '/index.html'
        if self.path == "/" or self.path == "/index.html":
            with open(os.path.join(sys.path[0], "html/index.html"), "r") as fh:
                self.send_response(200)
                self.send_header("Content-type", "text/html")
                self.end_headers()
                self.wfile.write(fh.read().encode())

        # Serve '/html/style.css'
        if self.path == "/css/style.css":
            with open(os.path.join(sys.path[0], "html/css/style.css"), "r") as fh:
                self.send_response(200)
                self.send_header("Content-type", "text/css")
                self.end_headers()
                self.wfile.write(fh.read().encode())

        # Serve '/json/defaultBrightness.json'
        if self.path.split("?")[0] == "/json/defaultBrightness.json":
            self.send_response(200)
            self.send_header("Content-type", "application/json")
            self.end_headers()
            defaultBrightness = read_data(
                I2C_ADDRESS, I2C_DEFAULT_BRT_STRUCT_REG, 3)
            # print(defaultBrightness)
            jsonData = json.dumps(defaultBrightness[::-1]).encode()
            # print(jsonData)
            self.wfile.write(jsonData)

        # Serve '/json/storedBrightness.json'
        if self.path.split("?")[0] == "/json/storedBrightness.json":
            self.send_response(200)
            self.send_header("Content-type", "application/json")
            self.end_headers()
            storedBrightness = read_data(
                I2C_ADDRESS, I2C_STORED_BRT_STRUCT_REG, 3)
            # print(storedBrightness)
            jsonData = json.dumps(storedBrightness[::-1]).encode()
            # print(jsonData)
            self.wfile.write(jsonData)

        # Serve '/json/testBrightness.json'
        if self.path.split("?")[0] == "/json/testBrightness.json":
            self.send_response(200)
            self.send_header("Content-type", "application/json")
            self.end_headers()
            testBrightness = read_data(
                I2C_ADDRESS, I2C_TEST_BRT_STRUCT_REG, 3)
            # print(testBrightness)
            jsonData = json.dumps(testBrightness[::-1]).encode()
            # print(jsonData)
            self.wfile.write(jsonData)

        # Route to save brightness
        if self.path.split("?")[0] == "/saveBrightness":
            query_components = parse_qs(urlparse(self.path).query)
            # print(query_components)
            brightness = eval(query_components["brightness"][0])
            # print("brightness: " + str(brightness))
            i2c_write_data(
                I2C_ADDRESS,
                I2C_STORED_BRT_STRUCT_REG,
                brightness,
                I2C_WRITE_REPETITION
            )
            self.send_response(200)
            self.send_header('Content-type', 'text/html')
            self.send_header('Custom-Info', 'Using standard send_response')
            self.end_headers()
            self.wfile.write("<h1>Hello, Standard HTTP!</h1>".encode())

        # Route to set brightness
        if self.path.split("?")[0] == "/setTestBrightness":
            query_components = parse_qs(urlparse(self.path).query)
            # print(query_components)
            index = eval(query_components["index"][0])
            # print("index: " + str(index))
            register = None
            if index == 0:
                register = I2C_TEST_PWR_LED_MIN_BRT_REG
            elif index == 1:
                register = I2C_TEST_PWR_LED_MAX_BRT_REG
            elif index == 2:
                register = I2C_TEST_SATA_LED_BRT_REG
            # print("register: " + str(register))
            brightness = eval(query_components["brightness"][0])
            # print("brightness: " + str(brightness))
            i2c_write_data(
                I2C_ADDRESS,
                register,
                brightness,
                I2C_WRITE_REPETITION
            )
            self.send_response(200)
            self.send_header('Content-type', 'text/html')
            self.send_header('Custom-Info', 'Using standard send_response')
            self.end_headers()
            self.wfile.write("<h1>Hello, Standard HTTP!</h1>".encode())
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
